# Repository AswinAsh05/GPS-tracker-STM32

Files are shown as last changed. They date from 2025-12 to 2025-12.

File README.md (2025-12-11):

## 📌 Project Overview

The **GPS Tracker Hardware – STM32F030 + SIM808** is a compact and production-ready embedded hardware design built for real-time location tracking applications.  
This board integrates a **32-bit STM32F030 microcontroller**, **SIM808 GSM+GPS module**, and a **wide-input power supply** on a **4-layer PCB** optimized for signal integrity, RF stability, and robust field performance.

This project demonstrates complete hardware engineering including:
- Full schematic development  
- RF-aware PCB routing  
- Power integrity optimization  
- SIM interface & protection circuitry  
- High-quality 3D modeling  
- Manufacturing-ready outputs (Gerber, Drill, STEP)

This repository provides everything required to **study, modify, manufacture, and extend** the hardware.

---

## 📷 PCB & 3D Model Previews

### 🔹 3D Model – Front View  
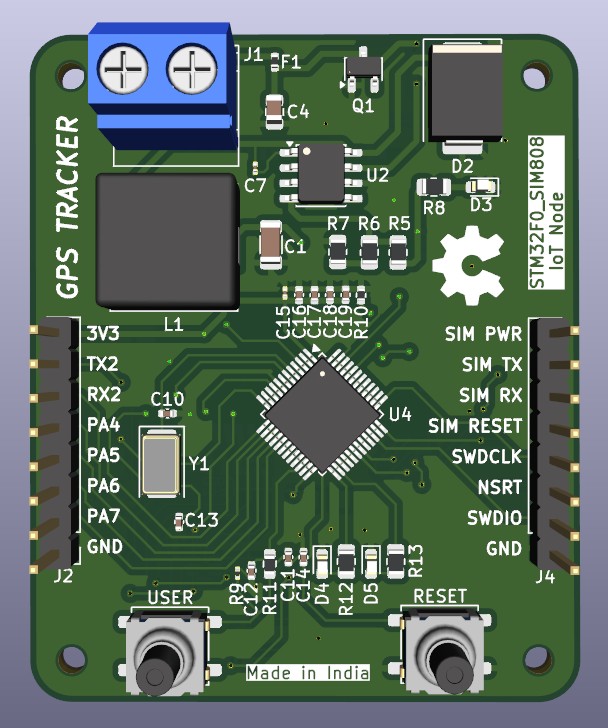
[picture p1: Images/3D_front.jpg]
3D Front


### 🔹 3D Model – Back View  
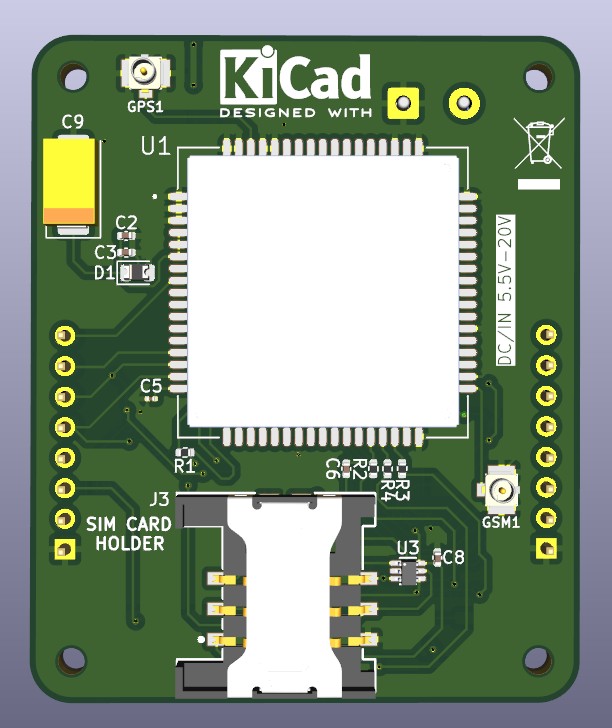
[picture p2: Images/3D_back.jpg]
3D Back


---

### 🔹 PCB Layout – Front Layer  
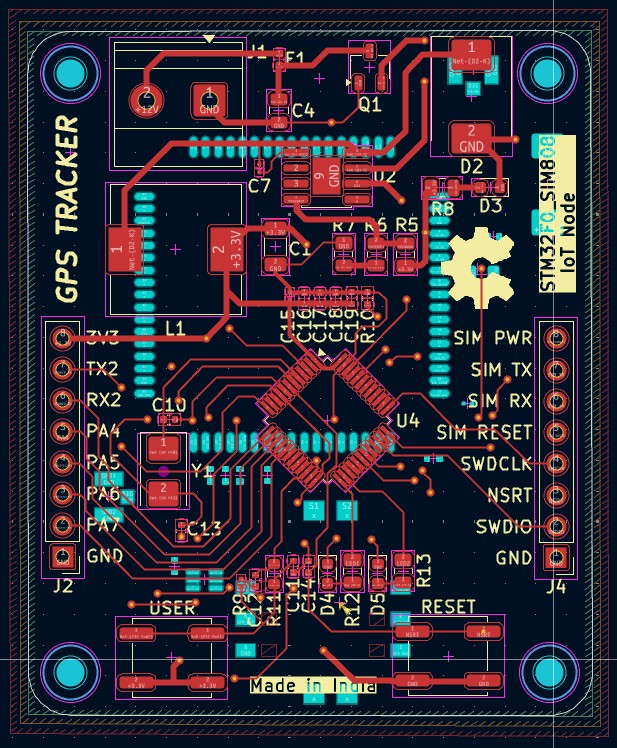
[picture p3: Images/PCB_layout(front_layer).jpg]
PCB Layout Front Layer


### 🔹 PCB Layout – Back Layer  
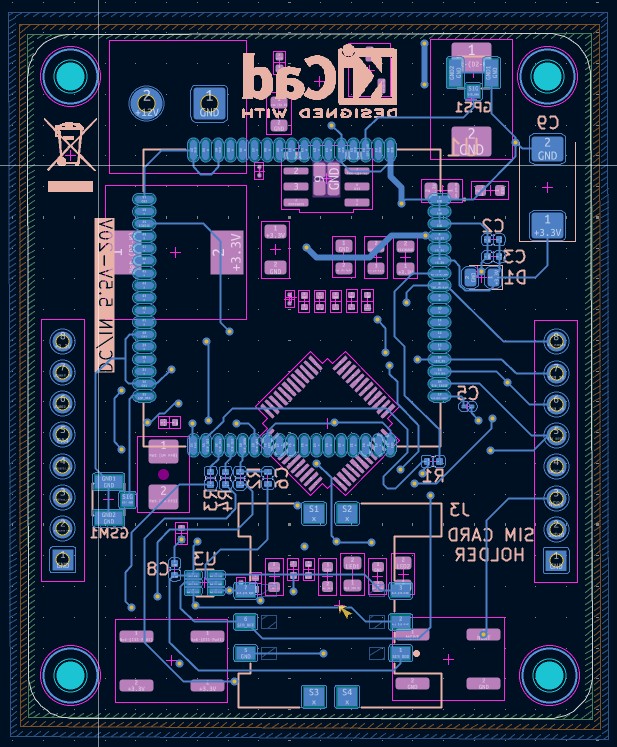
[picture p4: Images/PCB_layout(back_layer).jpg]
PCB Layout Back Layer


---

### 🔹 PCB Layout – Combined View  
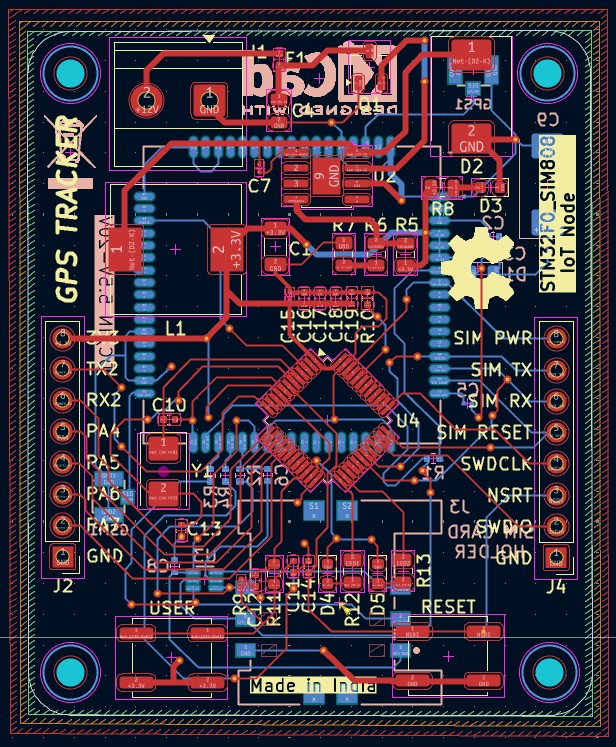
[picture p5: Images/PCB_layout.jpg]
PCB Layout


---

### 🔹 Schematic Overview  
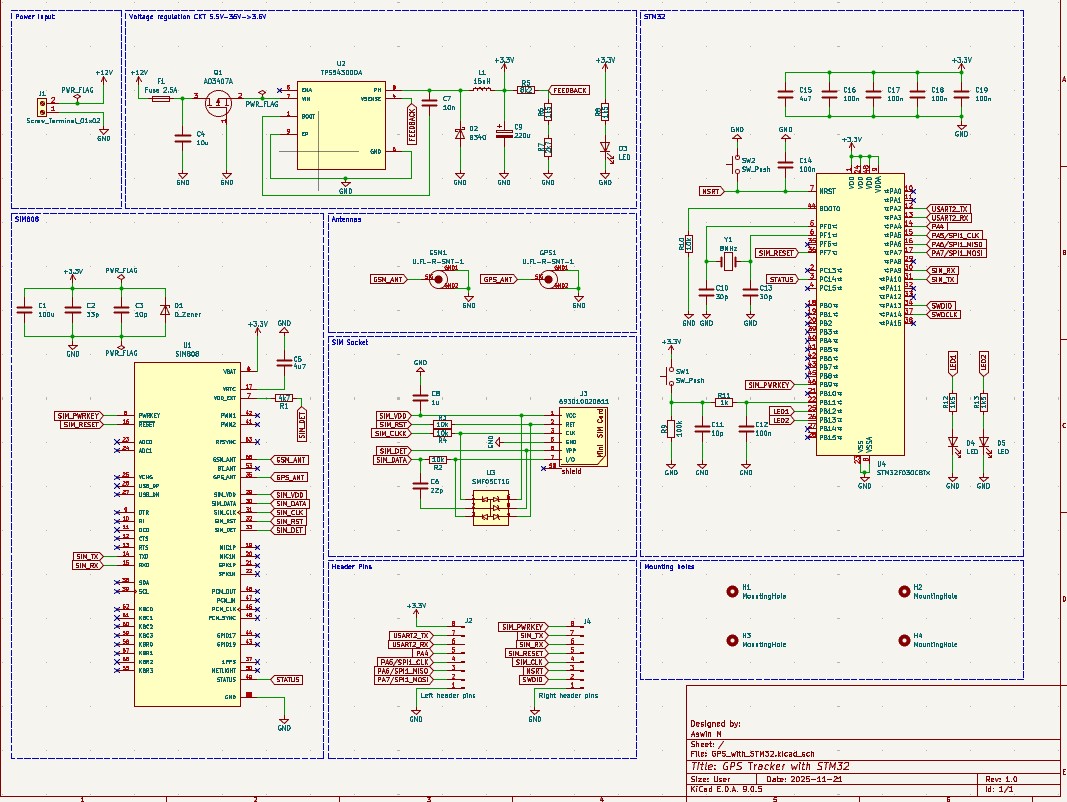
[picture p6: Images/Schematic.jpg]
Schematic


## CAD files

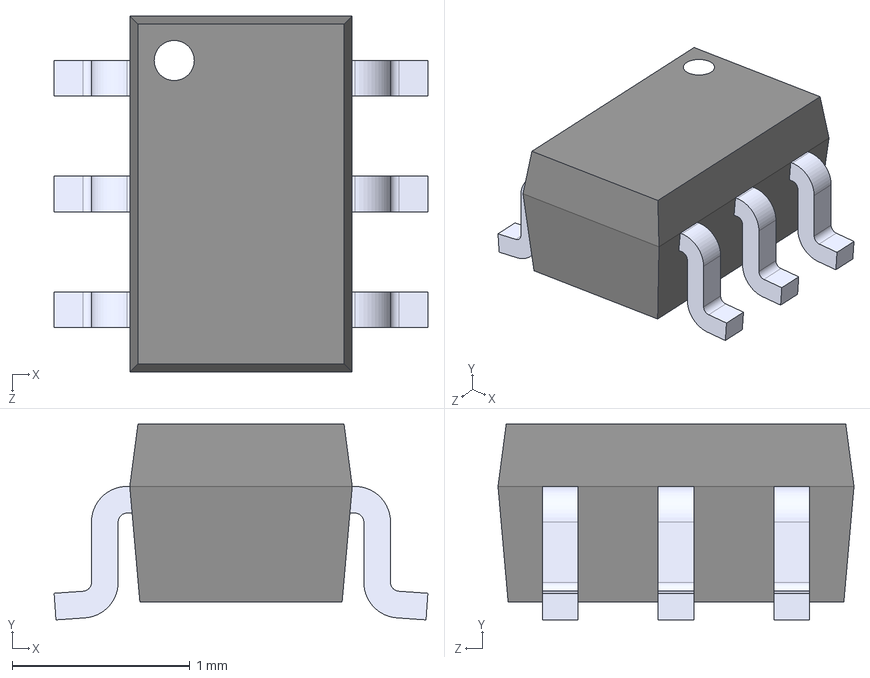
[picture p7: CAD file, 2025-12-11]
3D files/SMF05CT1G.step
2.10 x 1.10 x 2.00 mm

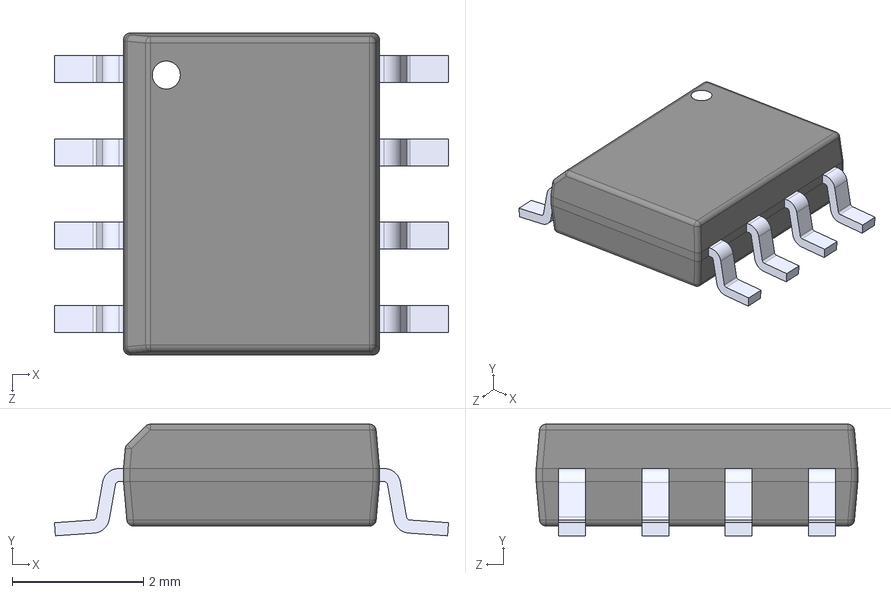
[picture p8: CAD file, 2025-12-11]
3D files/TPS5430DDA.step
6.00 x 1.70 x 4.90 mm

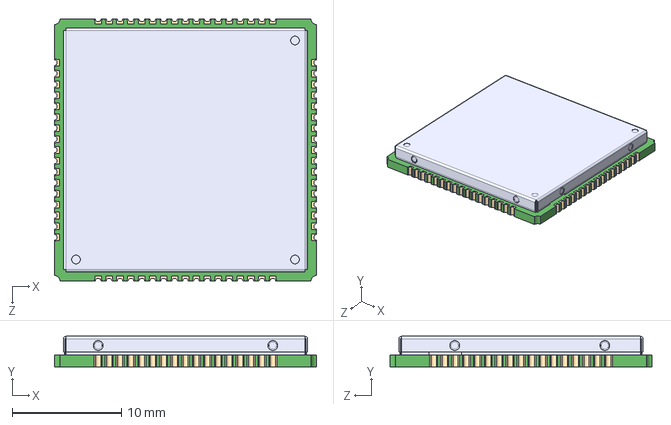
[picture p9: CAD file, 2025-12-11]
3D files/SIM808.step
24.0 x 2.80 x 24.0 mm

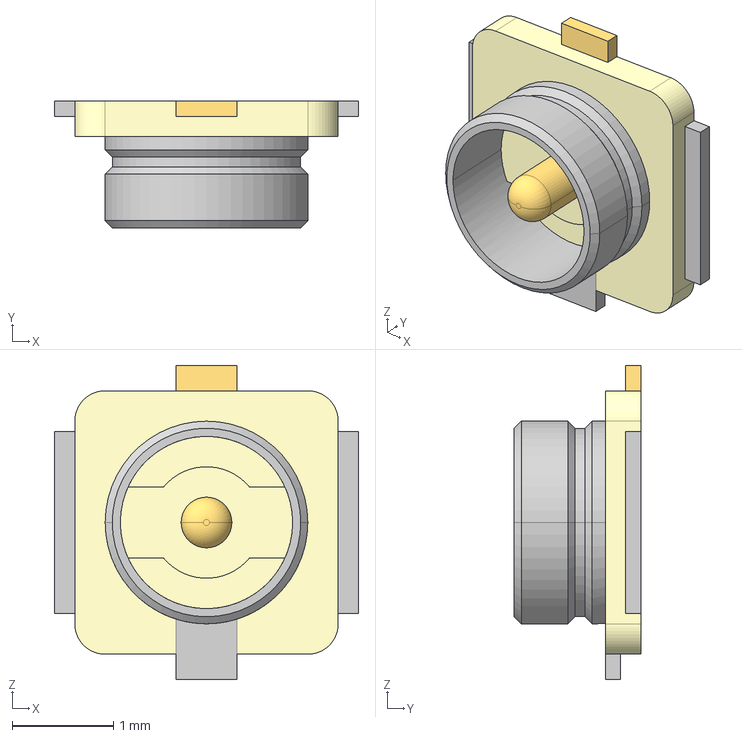
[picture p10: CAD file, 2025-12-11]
3D files/U.FL-R-SMT-1.step
3.00 x 1.25 x 3.10 mm

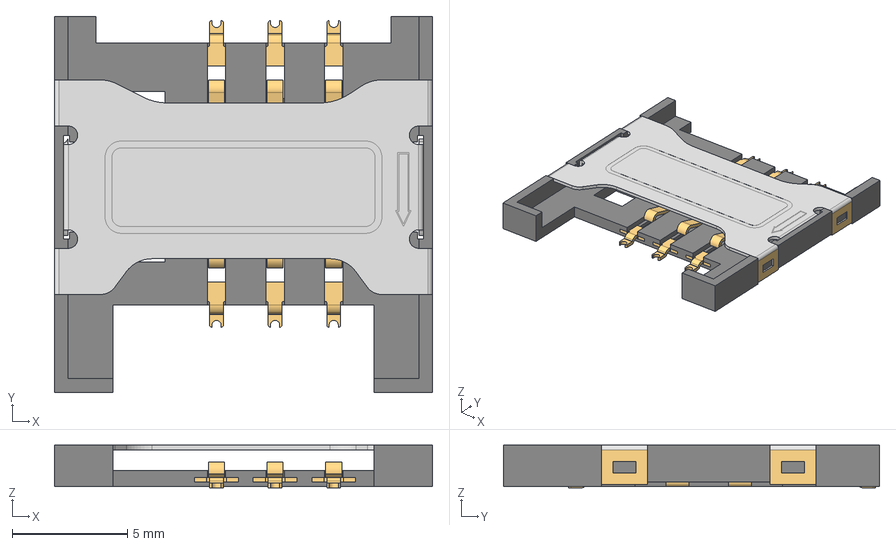
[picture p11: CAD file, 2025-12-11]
3D files/693010020611.step
16.4 x 16.3 x 1.85 mm
693010020611_CAP
693010020611_PIN2 x 6

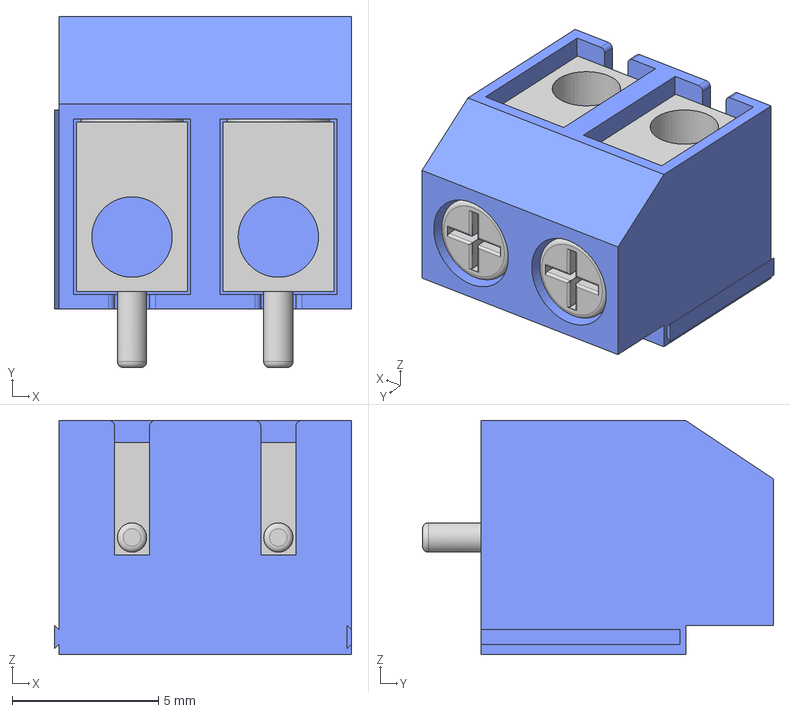
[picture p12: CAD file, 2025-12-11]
3D files/Screw Terminal Block 5mm Blue 2-way.step
10.2 x 12.0 x 8.00 mm

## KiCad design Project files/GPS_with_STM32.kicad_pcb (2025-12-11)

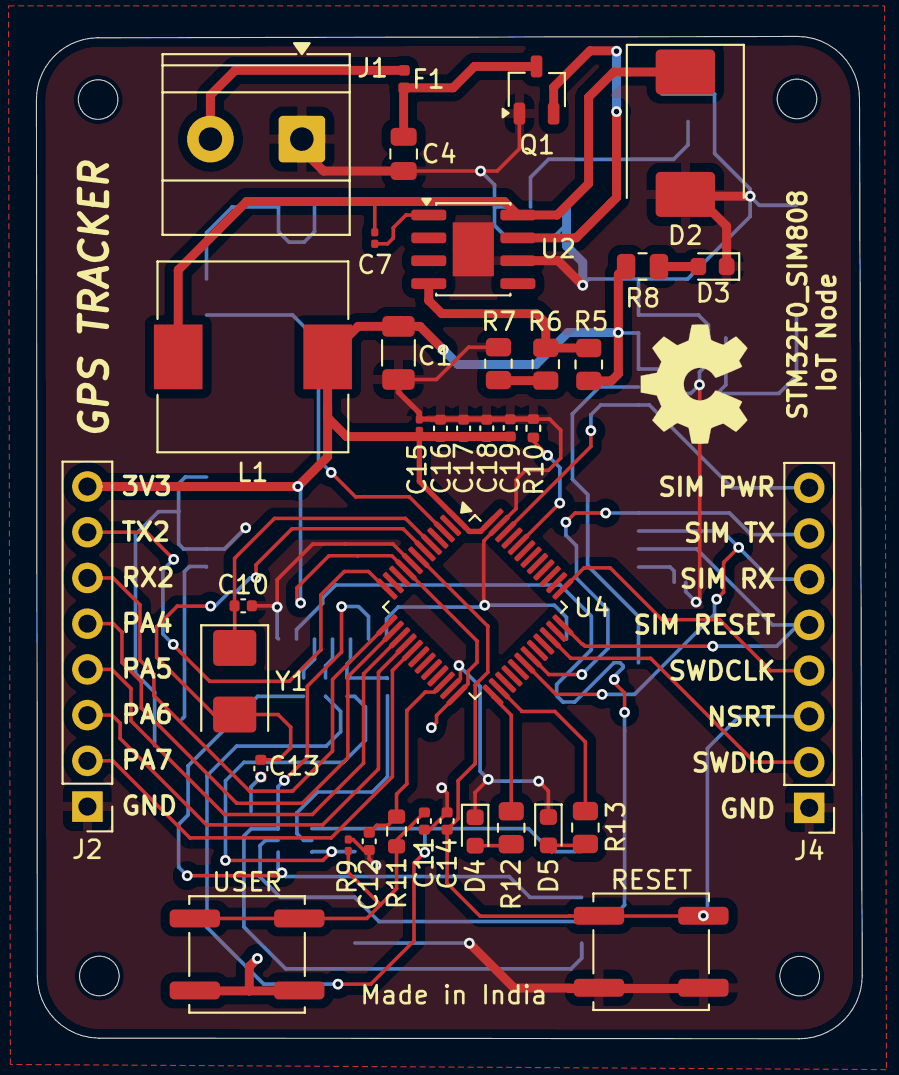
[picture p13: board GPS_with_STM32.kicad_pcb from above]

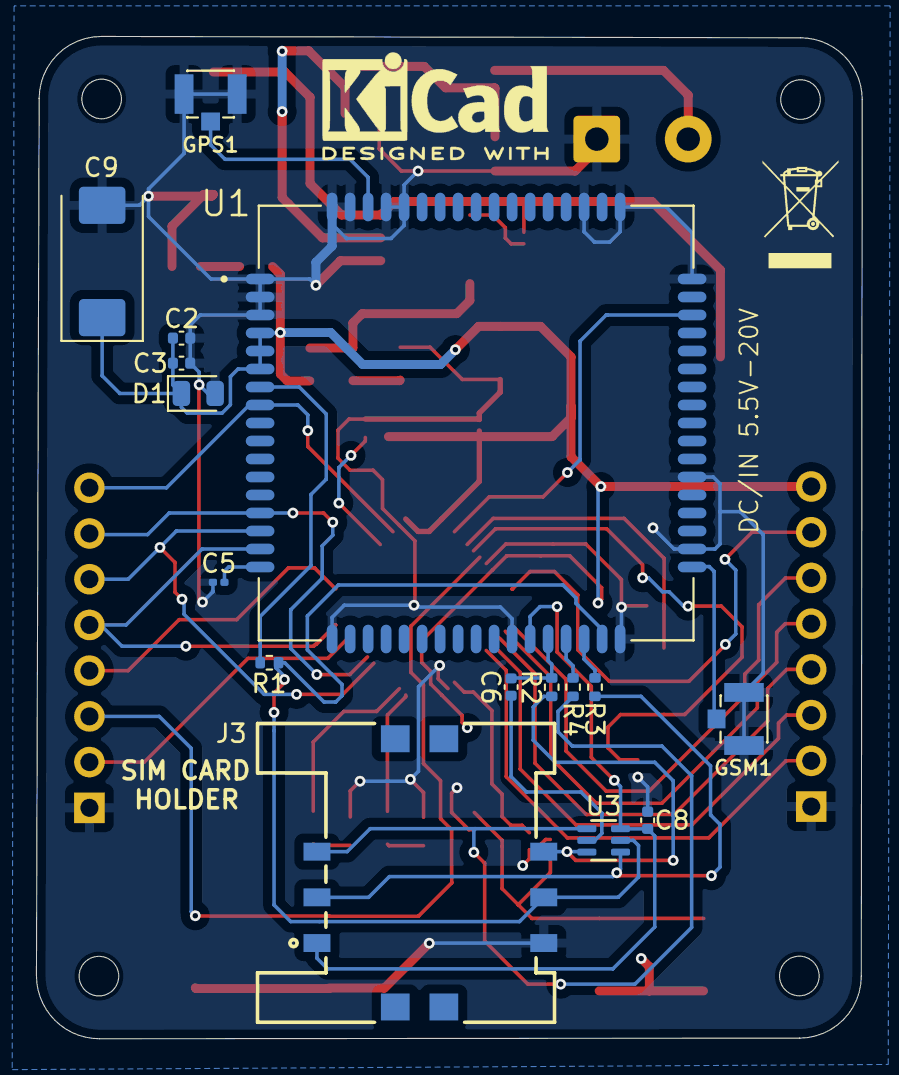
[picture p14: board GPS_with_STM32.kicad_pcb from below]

Board: 4 copper layers, 45.9 x 55.7 mm, 57 parts (16 on the bottom side), 46 nets.

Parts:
C1: 100u; C_1206_3216Metric
C2: 33p; C_0402_1005Metric
C3, C11: 10p; C_0402_1005Metric
C4: 10u; C_0805_2012Metric
C5, C15: 4u7; C_0201_0603Metric
C6: 22p; C_0402_1005Metric
C7: 10n; C_0201_0603Metric
C8: 1u; C_0402_1005Metric
C9: 220u; CP_EIA-7343-15_Kemet-W
C10, C13: 30p; C_0402_1005Metric
C12, C14, C16, C17, C18, C19: 100n; C_0402_1005Metric
D1: D_Zener; D_0805_2012Metric
D2: B340; D_SMC
D3, D4, D5: LED; LED_0603_1608Metric
F1: Fuse 2.5A; Fuse_0402_1005Metric
GPS1: U.FL-R-SMT-1
GSM1: U.FL-R-SMT-1
H1, H2, H3, H4: MountingHole; MountingHole_2.2mm_M2
J1: Screw_Terminal_01x02; TerminalBlock_Phoenix_MKDS-1,5-2-5.08_1x02_P5.08mm_Horizont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
J2: Left header pins; PinHeader_1x08_P2.54mm_Vertical
J3: 693010020611
J4: Right header pins; PinHeader_1x08_P2.54mm_Vertical
L1: 15uH; L_10.4x10.4_H4.8
Q1: AO3407A; TSOT-23
R1: 4k7; R_0402_1005Metric
R2, R3, R4, R10: 10k; R_0402_1005Metric
R5: 8k2; R_0805_2012Metric
R6, R8, R12, R13: 1k5; R_0805_2012Metric
R7: 2k7; R_0805_2012Metric
R9: 100k; R_0201_0603Metric
R11: 1k; R_0603_1608Metric
RESET: SW_Push; SW_Push_1P1T_NO_CK_KSC6xxJ
U1: SIM808; XCVR_SIM808
U2: TPS5430DDA; SOIC-8-1EP_3.9x4.9mm_P1.27mm_EP2.29x3mm
U3: SMF05CT1G; SOT65P210X110-6N
U4: STM32F030C8Tx; LQFP-48_7x7mm_P0.5mm
USER: SW_Push; SW_Push_1P1T_NO_CK_KSC6xxJ
Y1: 8MHz; Crystal_SMD_5032-2Pin_5.0x3.2mm

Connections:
+3.3V: C1.1, C2.1, C3.1, C9.1, C15.1, C16.1, C17.1, C18.1, C19.1, D1.1 (K), J2.8, L1.2, R5.1, R8.2, U1.4 (VBAT), U1.5 (VBAT), U1.6 (VBAT), U4.1 (VDD), U4.9 (VDDA), U4.24 (VDD), U4.48 (VDD), USER.2
+12V: F1.1, J1.2
FEEDBACK: R5.2, R6.2, U2.4 (VSENSE)
GND: C1.2, C2.2, C3.2, C4.2, C5.1, C8.1, C9.2, C10.2, C11.2, C12.2, C13.2, C14.1, C15.2, C16.2, C17.2, C18.2, C19.2, D1.2 (A), D2.2 (A), D3.1 (K), D4.1 (K), D5.1 (K), GPS1.GND1, GPS1.GND2, GSM1.GND1, GSM1.GND2, J1.1, J2.1, J3.5 (GND), J4.1, Q1.1 (G), R7.1, R9.1, R10.1, RESET.2, U1.1 (GND), U1.2 (GND), U1.3 (GND), U1.18 (GND), U1.28 (GND), U1.34 (GND), U1.36 (GND), U1.40 (GND), U1.51 (GND), U1.52 (GND), U1.54 (GND), U1.64 (GND), U1.65 (GND), U1.67 (GND), U1.68 (GND), U2.6 (GND), U2.9 (EP), U4.8 (VSSA), U4.23 (VSS), U4.47 (VSS)
GPS_ANT: GPS1.SIG, U1.66 (GSM_ANT)
GSM_ANT: GSM1.SIG, U1.35 (GPS_ANT)
LED1: R12.2, U4.25 (PB12)
LED2: R13.2, U4.26 (PB13)
NSRT: C14.2, J4.3, RESET.1, U4.7 (NRST)
unnamed: C6.2, U3.2
unnamed: C11.1, R9.2, R11.1, USER.1
unnamed: C7.1, D2.1 (K), L1.1, U2.8 (PH)
unnamed: D3.2 (A), R8.1
unnamed: D4.2 (A), R12.1
unnamed: D5.2 (A), R13.1
unnamed: J3.3 (CLK), R4.2, U3.1
unnamed: J3.7 (I/O), R2.2, U3.3
unnamed: J3.2 (RET), R3.2, U3.4
unnamed: C4.1, F1.2, Q1.3 (D)
unnamed: Q1.2 (S), U2.7 (VIN)
unnamed: R6.1, R7.2
unnamed: R1.1, U1.7 (VDD_EXT)
unnamed: C5.2, U1.17 (VRTC)
unnamed: C7.2, U2.1 (BOOT)
unnamed: R10.2, U4.44 (BOOT0)
unnamed: C12.1, R11.2, U4.22 (PB11)
unnamed: C10.1, U4.5 (PF0), Y1.1
unnamed: C13.1, U4.6 (PF1), Y1.2
PA4: J2.5, U4.14 (PA4)
PA5/SPI1_CLK: J2.4, U4.15 (PA5)
PA6/SPI1_MISO: J2.3, U4.16 (PA6)
PA7/SPI1_MOSI: J2.2, U4.17 (PA7)
SIM_CLK: R4.1, U1.31 (SIM_CLK)
SIM_DATA: C6.1, R2.1, U1.30 (SIM_DATA)
SIM_DET: J3.6 (VPP), R1.2, U1.33 (SIM_DET), U3.5
SIM_PWRKEY: J4.8, U1.8 (PWRKEY), U4.46 (PB9)
SIM_RESET: J4.5, U1.16 (~RESET), U4.36 (PF7)
SIM_RST: R3.1, U1.32 (SIM_RST)
SIM_RX: J4.6, U1.15 (RXD), U4.30 (PA9)
SIM_TX: J4.7, U1.14 (TXD), U4.31 (PA10)
SIM_VDD: C8.2, J3.1 (VCC), U1.29 (SIM_VDD), U3.6
STATUS: U1.49 (STATUS), U4.3 (PC14)
SWDCLK: J4.4, U4.37 (PA14)
SWDIO: J4.2, U4.34 (PA13)
USART2_RX: J2.6, U4.13 (PA3)
USART2_TX: J2.7, U4.12 (PA2)
